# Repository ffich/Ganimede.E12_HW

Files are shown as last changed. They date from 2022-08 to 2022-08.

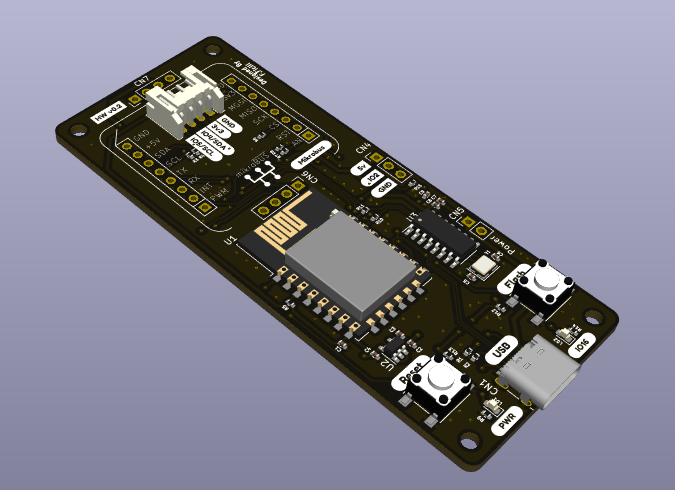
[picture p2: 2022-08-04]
50_3D/Ganimede.E12.png

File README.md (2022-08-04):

# Ganimede.E12_HW
Public repo for ganimede.E12 hardware project.

# What Ganimede is?
The Ganimede is a family of fancy development boards based on ESP8266 and ESP32 SoC from EspressIf.
The idea behind Ganimede is that I started to be bored of soldering, breadboarding and, more in general, to have messy connection between my development board and the sensor and actuators I needed for my experiments and projects.
Additionally, after the experience with Mercury System, I decided to not to do again such a crazy thing in which I had to make all the HW and SW, as it required literally hundreds of days and it's not sustainable (and even if it would be, Anna would probably kill me). Moreover, I do love C, but I understand that this is not the same for everybody and is also a bit limiting, so welcome to Python and Javascript. Last but not least, I wanted to have something really cheap, that can be used by me, friends and (possibly) others.
So, in the end, Ganimede is a development board with the following characteristics:

1. It's based on ESP SoC with integrated peripherals like WiFi, BT and USB.
2. It carries some sockets/connectors that allow to use well known standards (Mikroe MikroBUS, SeedStudio grove, others), so no more messy connections with sensor/actuators around your desk.
3. Can be programmed in C/C++, Python and Javascript.
4. It's really cheap.
5. It's open hardware, I will share schematics and design files.
6. It's really simple to use.

# Ganimede.E12
Ganimede.E12 is the version based on ESP8266 (more specifically on the ESP-12 module by AI-Thinker). The hardware details of Ganimede.E12 are resumed in the picture below:

HwDetails

## Main characteristics of Ganimede.E12:
- USB connection for communication, Power and Flashing
- WiFi
- 11x GPIO
- 2x User LEDs
- 2x User buttons
- 1x MikroBUS Socket
- 1x Grove Connector
- 1x Neopixel/1-wire Connector
- 2x OLED Connectors

If you want more information you can have a look at the [Ganimede.E12 Datasheet](https://2492ae4f-d323-49c0-bc1e-8d5936f83a9d.usrfiles.com/ugd/2492ae_11933c1aee514b55b51fd540d7772119.pdf) and to the [Ganimede.E12 Product Page](https://frafich.wixsite.com/jupitersystem/product-page/ganimede-e12).

# Ganimede.E12 HW project
This repo contains the full HW project of Ganimede.E12, with the traditional file structure I use on my HW projects, and more specifically:
- 10_PCB: contains the Kicad 6.x project of the board. The **jlcpcb** folder contains all the files needed for making the board using JLCPCB service.
- 20_SCH: contains the board's schematic in PDF.
- 30_BOMS: contains a fancy iBOM (made using the iBOM plugin by [https://github.com/openscopeproject](https://github.com/openscopeproject)) and a more traditional BOM file.
- 40_GERBERS: contains Gerber and Centronic files. These files allow you to make your own board by yourself or using traditional PCB/Manufacturing services (e.g. PcbWay).
- 50_3D: contains a 3D view of the board.
- 60_LIB: contains some additional 3D files (mostly step) I needed for making the board's 3D.

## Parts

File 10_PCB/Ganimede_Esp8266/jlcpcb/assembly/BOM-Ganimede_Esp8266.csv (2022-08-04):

Comment | Designator | Footprint | LCSC
1k | R14,R9 | R_0402_1005Metric | C11702
Flash | SW1,SW2 | SW_Push_1P1T_NO_6x6mm_H9.5mm | C127509
CH340G | U3 | SOIC-16_3.9x9.9mm_P1.27mm | C14267
100nF | C1,C8,C9 | C_0402_1005Metric | C1525
470pF | C3 | C_0402_1005Metric | C1537
12pF | C5,C6 | C_0402_1005Metric | C1547
10uF | C4,C7 | C_0402_1005Metric | C15525
USB_C | CN1 | USB_C_Receptacle_HRO_TYPE-C-31-M-12 | C165948
Pwr | LD1 | LED_0603_1608Metric | C2286
User | LD2 | LED_0603_1608Metric | C2288
470 | R10,R11 | R_0402_1005Metric | C25117
100k | R8 | R_0402_1005Metric | C25741
10k | R12,R13,R15,R3,R4,R5,R6 | R_0402_1005Metric | C25744
220k | R7 | R_0402_1005Metric | C25767
5k1 | R1,R2 | R_0402_1005Metric | C25905
1uF | C2 | C_0402_1005Metric | C52923
ESP-12F | U1 | ESP-12E | C82891
Crystal | Y1 | Crystal_SMD_3225-4Pin_3.2x2.5mm | C9002
SPX3819M5-L-3-3 | U2 | SOT-23-5 | C9055

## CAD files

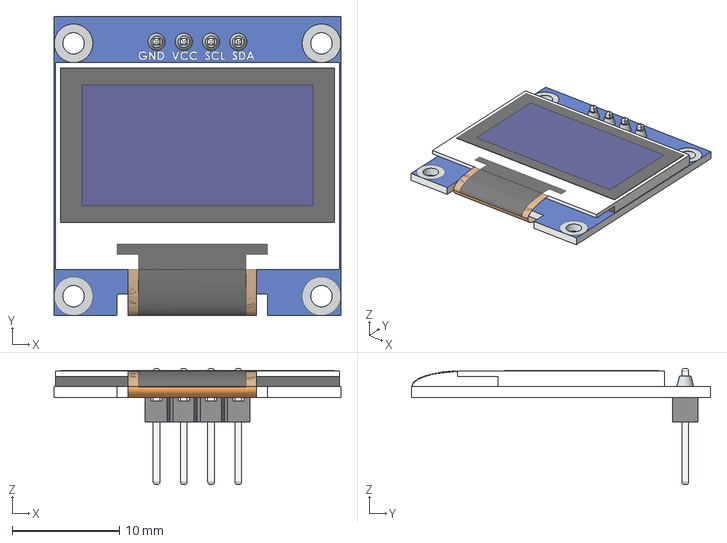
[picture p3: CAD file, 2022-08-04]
60_LIB/30_3d/OLED-128x64-0.96.step
26.7 x 27.9 x 10.8 mm

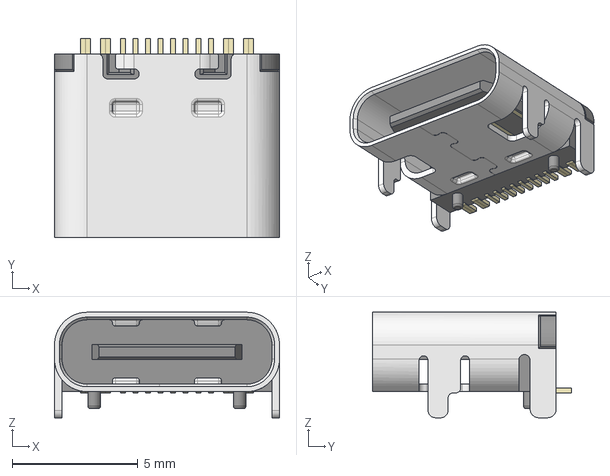
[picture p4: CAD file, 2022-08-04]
60_LIB/30_3d/HRO_TYPE-C-31-M-12.step
8.95 x 7.90 x 4.20 mm

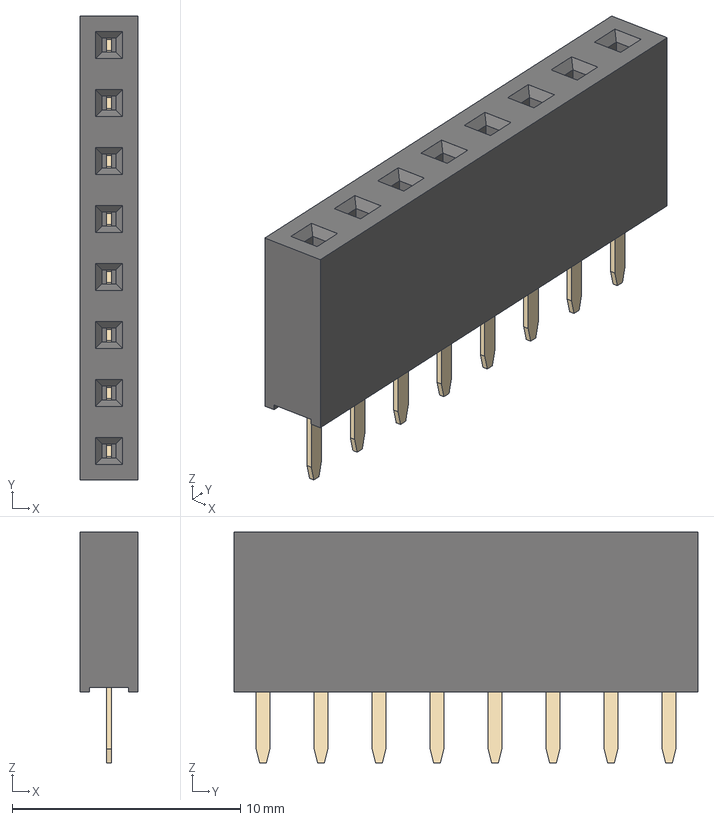
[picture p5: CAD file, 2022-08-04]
60_LIB/30_3d/PinSocket_1x08_P2.54mm_Vertical.step
2.54 x 20.3 x 10.1 mm

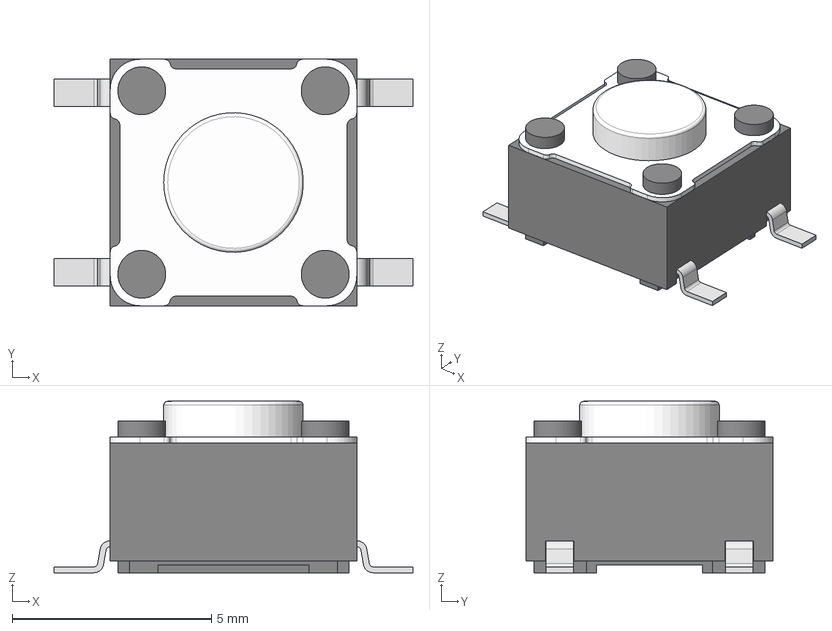
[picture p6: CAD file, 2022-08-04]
60_LIB/30_3d/430182043816 (rev1).stp
9.00 x 6.20 x 4.30 mm

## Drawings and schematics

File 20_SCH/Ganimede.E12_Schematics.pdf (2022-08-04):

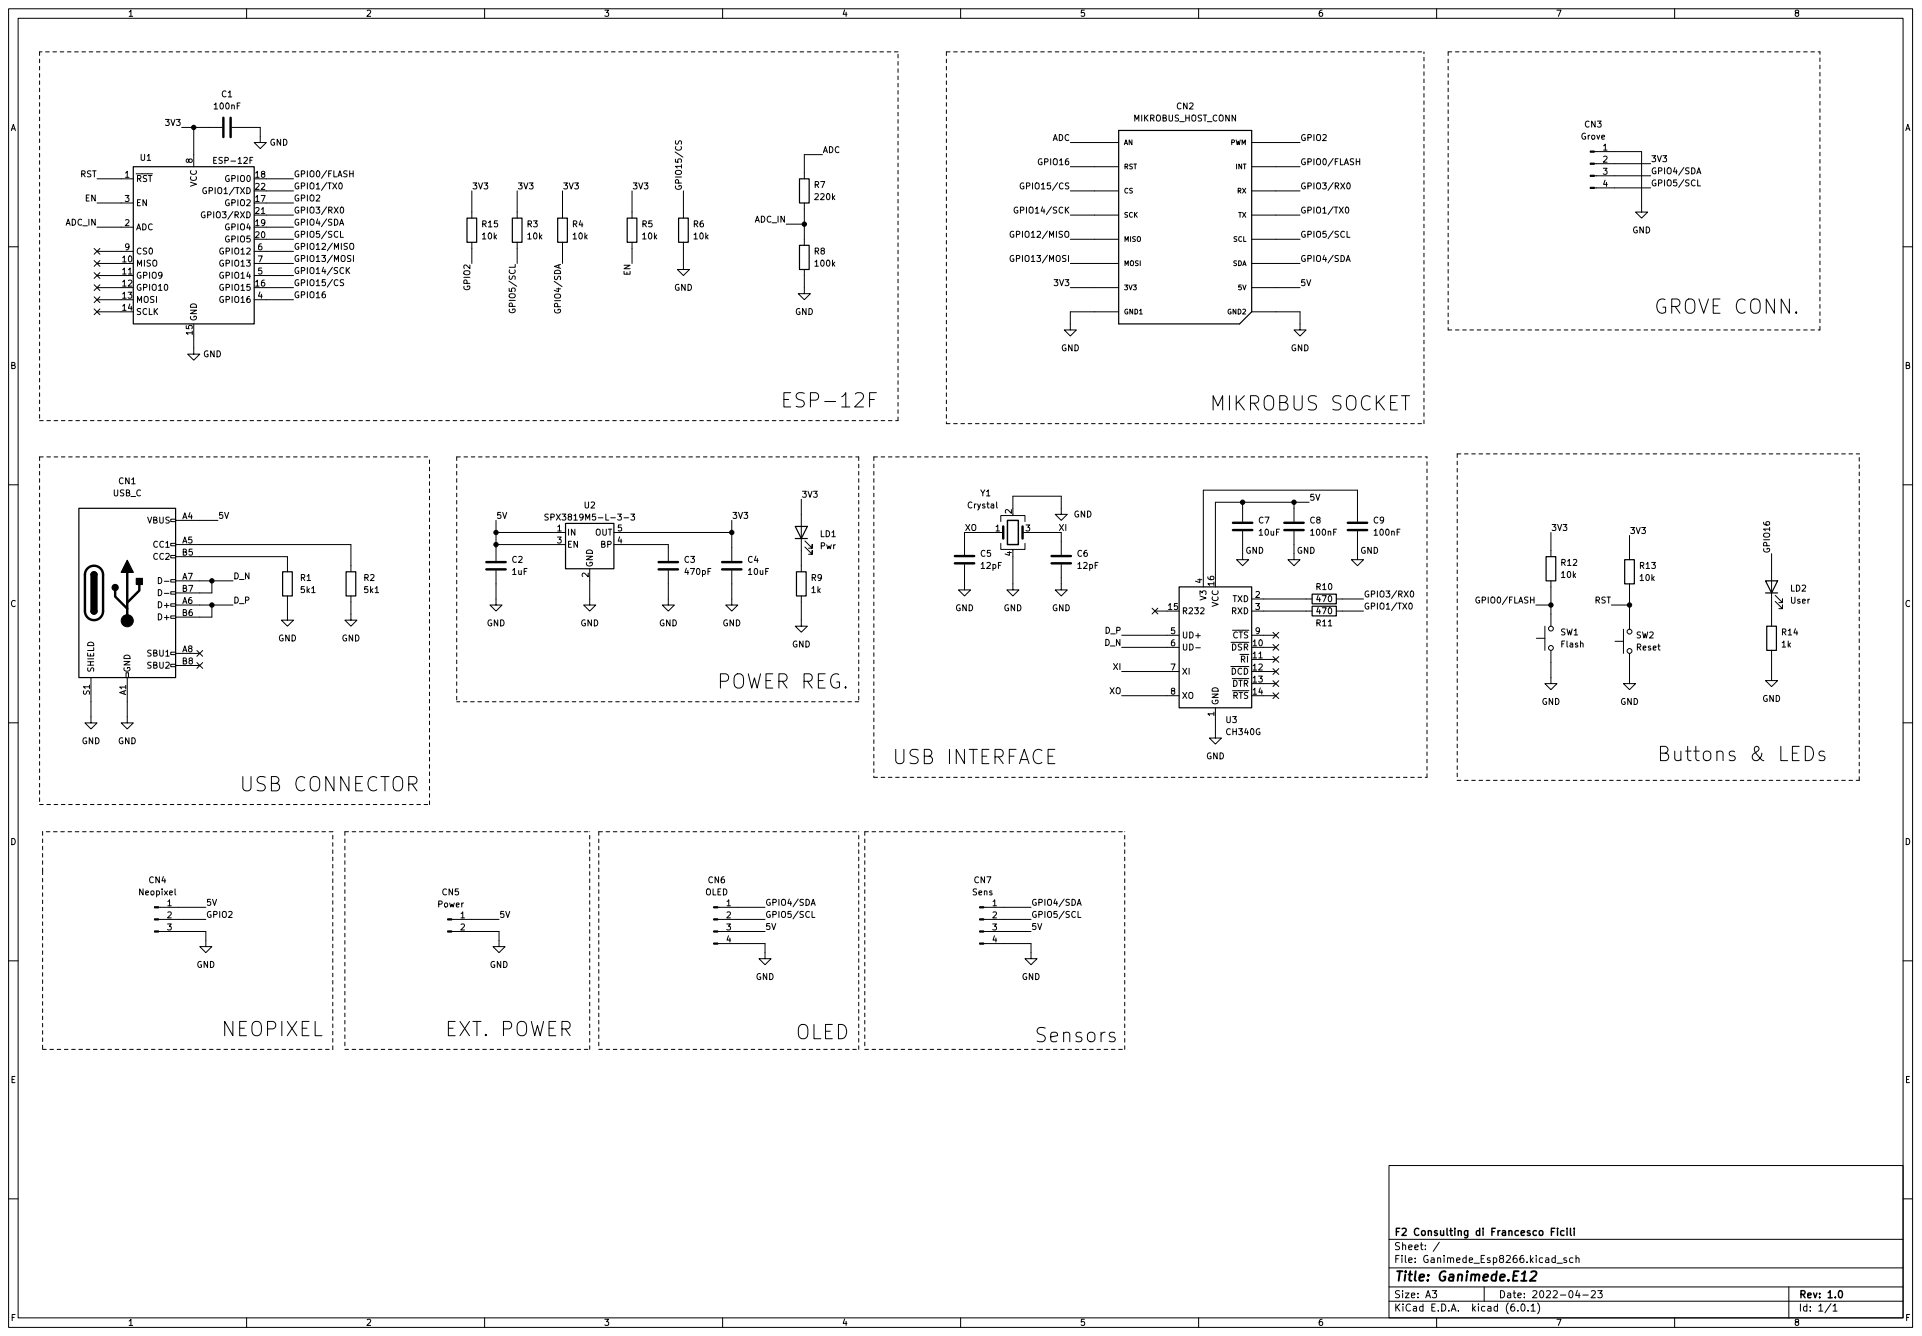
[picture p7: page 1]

2 EN 3 BP 4 OUT 5 U2 SPX3819M5-L-3-3 GND

1 ~{DSR}10 ~{RI}11 ~{DCD}12 ~{DTR}13 ~{RTS}14 R232 15 VCC 16 TXD 2 RXD 3 V3

4 UD+ 5 UD- 6 XI 7 XO 8 ~{CTS} 9 U3CH340G

File: Ganimede_Esp8266.kicad_sch Sheet: / F2 Consulting di Francesco Ficili

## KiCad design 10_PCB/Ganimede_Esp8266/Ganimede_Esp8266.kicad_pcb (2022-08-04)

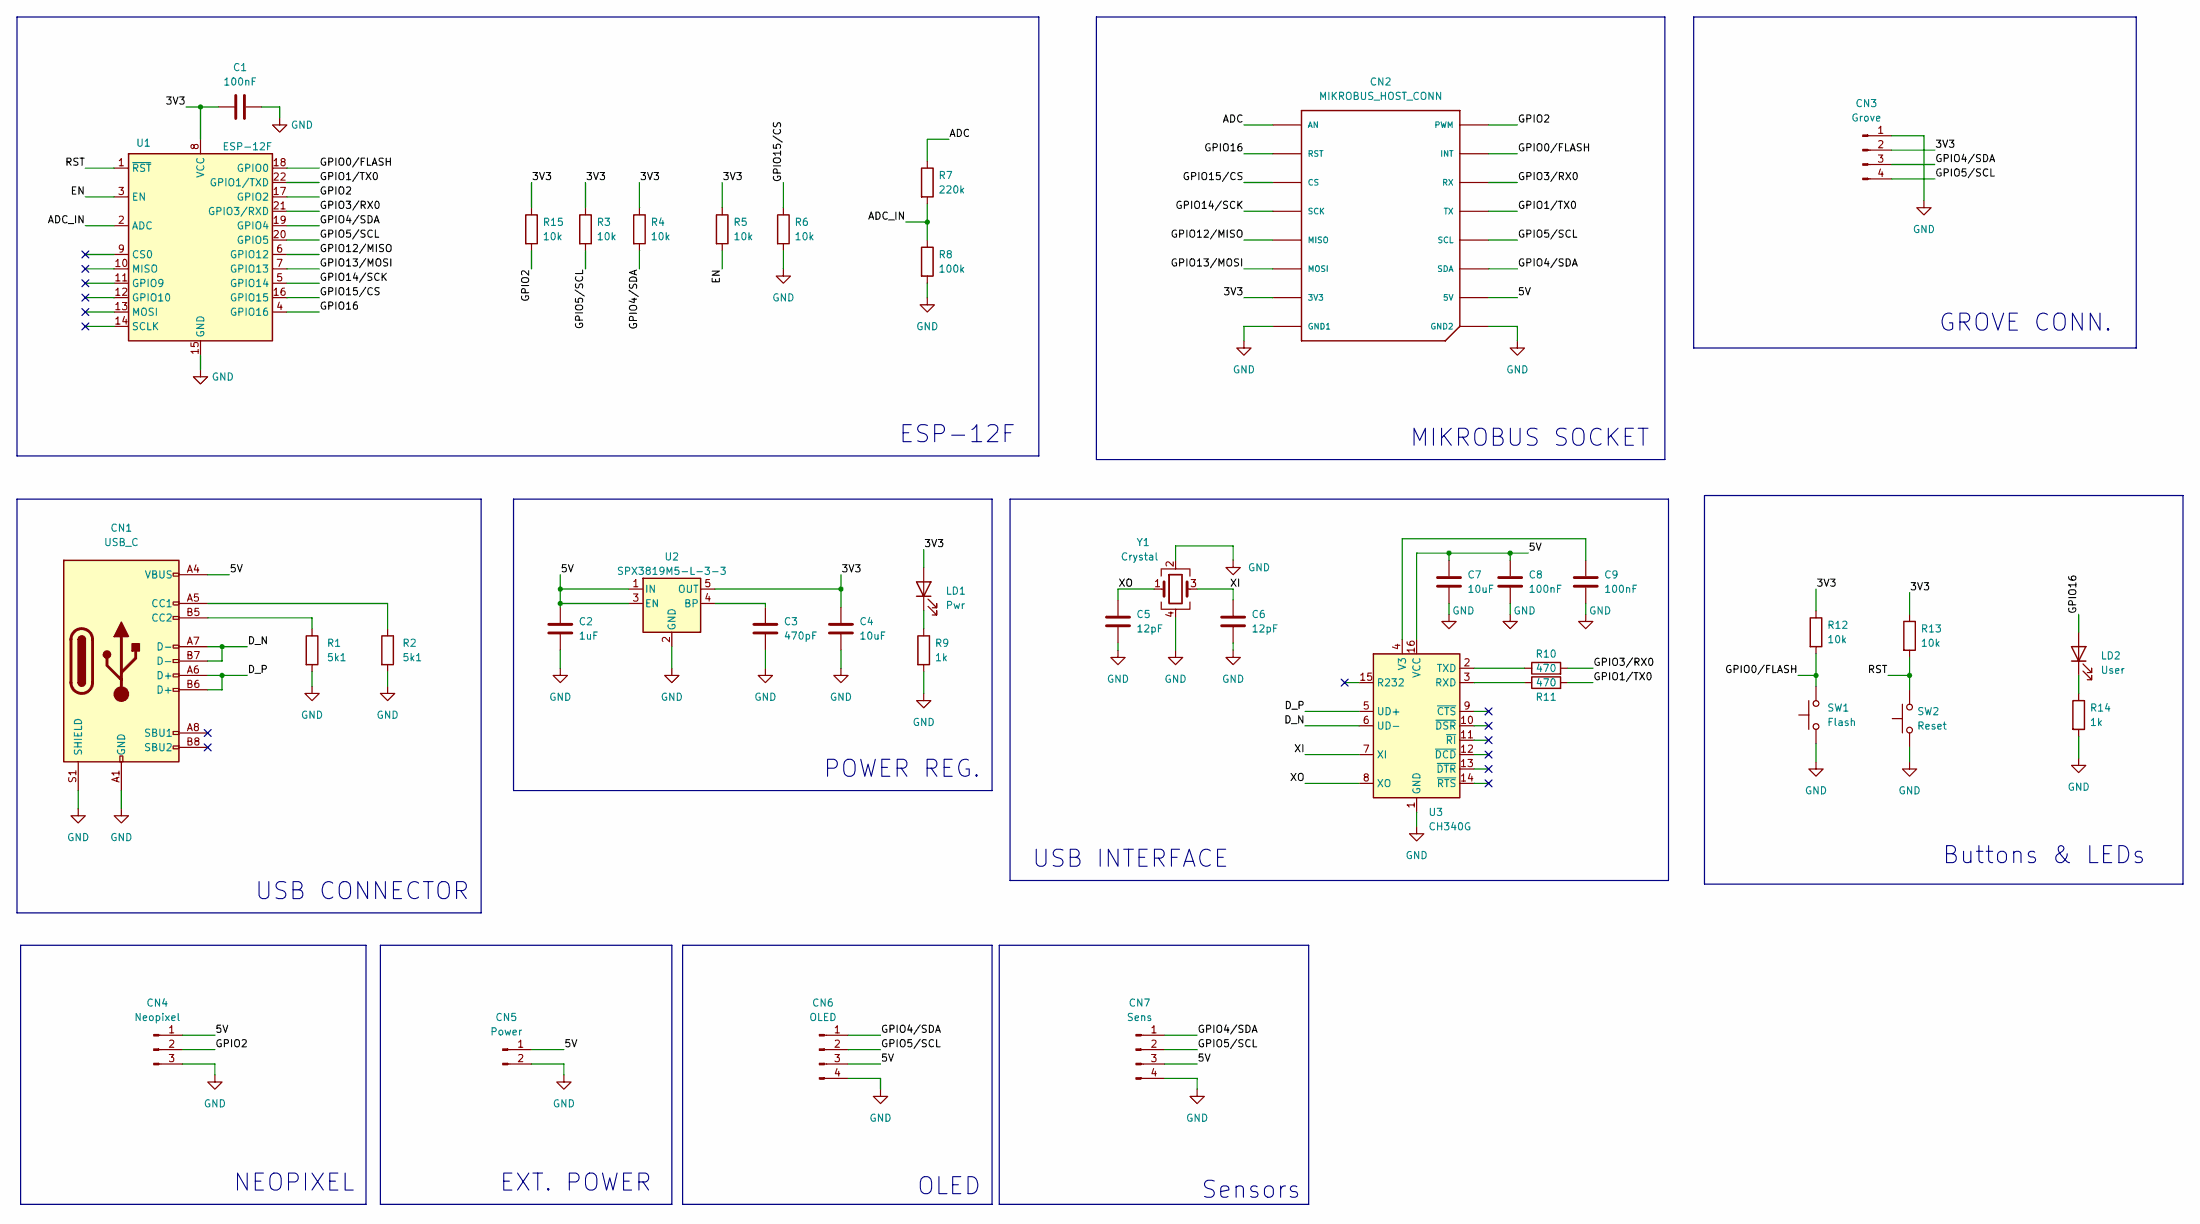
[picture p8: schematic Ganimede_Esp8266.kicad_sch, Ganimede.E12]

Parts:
C1, C8, C9: 100nF; C_0402_1005Metric; LCSC C1525
C2: 1uF; C_0402_1005Metric; LCSC C52923
C3: 470pF; C_0402_1005Metric; LCSC C1537
C4, C7: 10uF; C_0402_1005Metric; LCSC C15525
C5, C6: 12pF; C_0402_1005Metric; LCSC C1547
CN1: USB_C; USB_C_Receptacle_HRO_TYPE-C-31-M-12; LCSC C165948
CN2: MIKROBUS_HOST_CONN
CN3: Grove; JST_PH_S4B-PH-K_1x04_P2.00mm_Horizontal
CN4: Neopixel; PinHeader_1x03_P2.54mm_Vertical
CN5: Power; PinHeader_1x02_P2.54mm_Vertical
CN6: OLED; PinHeader_1x04_P2.54mm_Vertical
CN7: Sens; PinHeader_1x04_P2.54mm_Vertical
LD1: Pwr; LED_0603_1608Metric; LCSC C2286
LD2: User; LED_0603_1608Metric; LCSC C2288
R1, R2: 5k1; R_0402_1005Metric; LCSC C25905
R3, R4, R5, R6, R12, R13, R15: 10k; R_0402_1005Metric; LCSC C25744
R7: 220k; R_0402_1005Metric; LCSC C25767
R8: 100k; R_0402_1005Metric; LCSC C25741
R9, R14: 1k; R_0402_1005Metric; LCSC C11702
R10, R11: 470; R_0402_1005Metric; LCSC C25117
SW1: Flash; SW_Push_1P1T_NO_6x6mm_H9.5mm; LCSC C127509
SW2: Reset; SW_Push_1P1T_NO_6x6mm_H9.5mm; LCSC C127509
U1: ESP-12F; ESP-12E; LCSC C82891
U2: SPX3819M5-L-3-3; SOT-23-5; LCSC C9055
U3: CH340G; SOIC-16_3.9x9.9mm_P1.27mm; LCSC C14267
Y1: Crystal; Crystal_SMD_3225-4Pin_3.2x2.5mm; LCSC C9002

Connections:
/3V3: C1.1, C4.1, CN2.P7 (3V3), CN3.2, LD1.2 (A), R3.1, R4.1, R5.1, R12.1, R13.1, R15.1, U1.8 (VCC), U2.5 (OUT)
/5V: C2.1, C7.1, C8.1, CN1.A4 (VBUS), CN1.A9 (VBUS), CN1.B4 (VBUS), CN1.B9 (VBUS), CN2.P10 (5V), CN4.1, CN5.1, CN6.3, CN7.3, U2.1 (IN), U2.3 (EN), U3.16 (VCC)
/ADC: CN2.P1 (AN), R7.1
/ADC_IN: R7.2, R8.1, U1.2 (ADC)
/D_N: CN1.A7 (D-), CN1.B7 (D-), U3.6 (UD-)
/D_P: CN1.A6 (D+), CN1.B6 (D+), U3.5 (UD+)
/EN: R5.2, U1.3 (EN)
/GPIO0/FLASH: CN2.P15 (INT), R12.2, SW1.2, U1.18 (GPIO0)
/GPIO1/TX0: CN2.P13 (TX), R11.2, U1.22 (GPIO1/TXD)
/GPIO2: CN2.P16 (PWM), CN4.2, R15.2, U1.17 (GPIO2)
/GPIO3/RX0: CN2.P14 (RX), R10.2, U1.21 (GPIO3/RXD)
/GPIO4/SDA: CN2.P11 (SDA), CN3.3, CN6.1, CN7.1, R4.2, U1.19 (GPIO4)
/GPIO5/SCL: CN2.P12 (SCL), CN3.4, CN6.2, CN7.2, R3.2, U1.20 (GPIO5)
/GPIO12/MISO: CN2.P5 (MISO), U1.6 (GPIO12)
/GPIO13/MOSI: CN2.P6 (MOSI), U1.7 (GPIO13)
/GPIO14/SCK: CN2.P4 (SCK), U1.5 (GPIO14)
/GPIO15/CS: CN2.P3 (CS), R6.1, U1.16 (GPIO15)
/GPIO16: CN2.P2 (RST), LD2.2 (A), U1.4 (GPIO16)
/RST: R13.2, SW2.2, U1.1 (~RST)
/XI: C6.1, U3.7 (XI), Y1.3
/XO: C5.1, U3.8 (XO), Y1.1
GND: C1.2, C2.2, C3.2, C4.2, C5.2, C6.2, C7.2, C8.2, C9.2, CN1.A1 (GND), CN1.A12 (GND), CN1.B1 (GND), CN1.B12 (GND), CN1.S1 (SHIELD), CN2.P8 (GND1), CN2.P9 (GND2), CN3.1, CN4.3, CN5.2, CN6.4, CN7.4, R1.2, R2.2, R6.2, R8.2, R9.2, R14.2, SW1.1, SW2.1, U1.15 (GND), U2.2 (GND), U3.1 (GND), Y1.2, Y1.4
unnamed: C3.1, U2.4 (BP)
unnamed: C9.1, U3.4 (V3)
unnamed: CN1.A5 (CC1), R2.1
unnamed: CN1.B5 (CC2), R1.1
unnamed: LD1.1 (K), R9.1
unnamed: LD2.1 (K), R14.1
unnamed: R10.1, U3.2 (TXD)
unnamed: R11.1, U3.3 (RXD)

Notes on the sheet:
GROVE CONN.
ESP-12F
Buttons & LEDs
POWER REG.
OLED
USB CONNECTOR
EXT. POWER
Sensors
NEOPIXEL
MIKROBUS SOCKET
USB INTERFACE

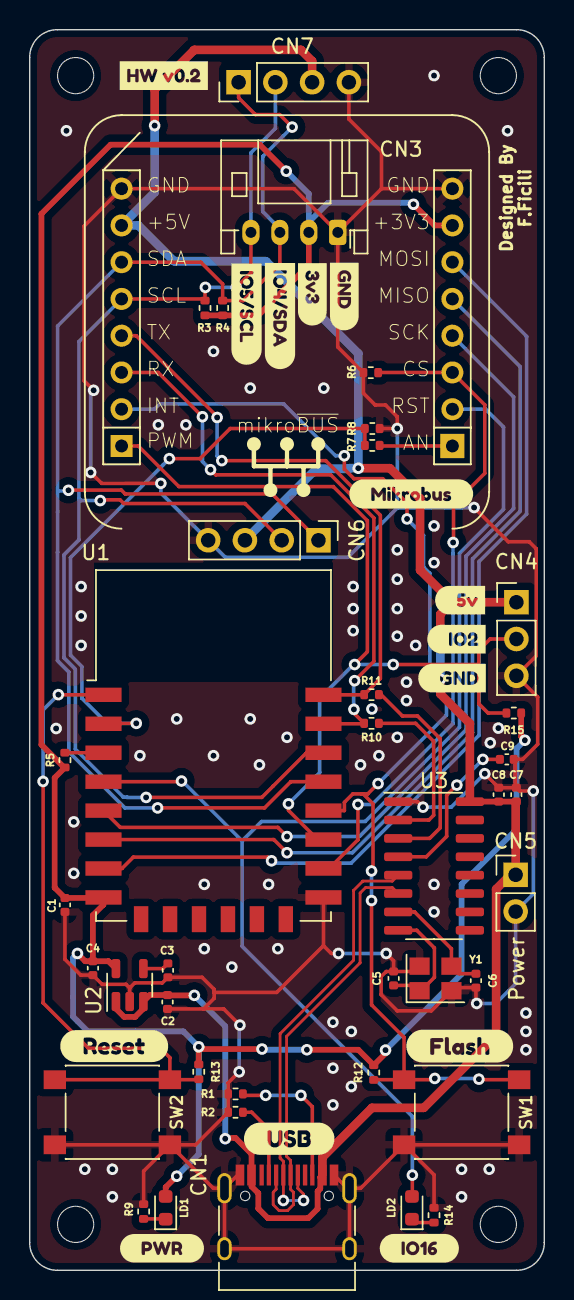
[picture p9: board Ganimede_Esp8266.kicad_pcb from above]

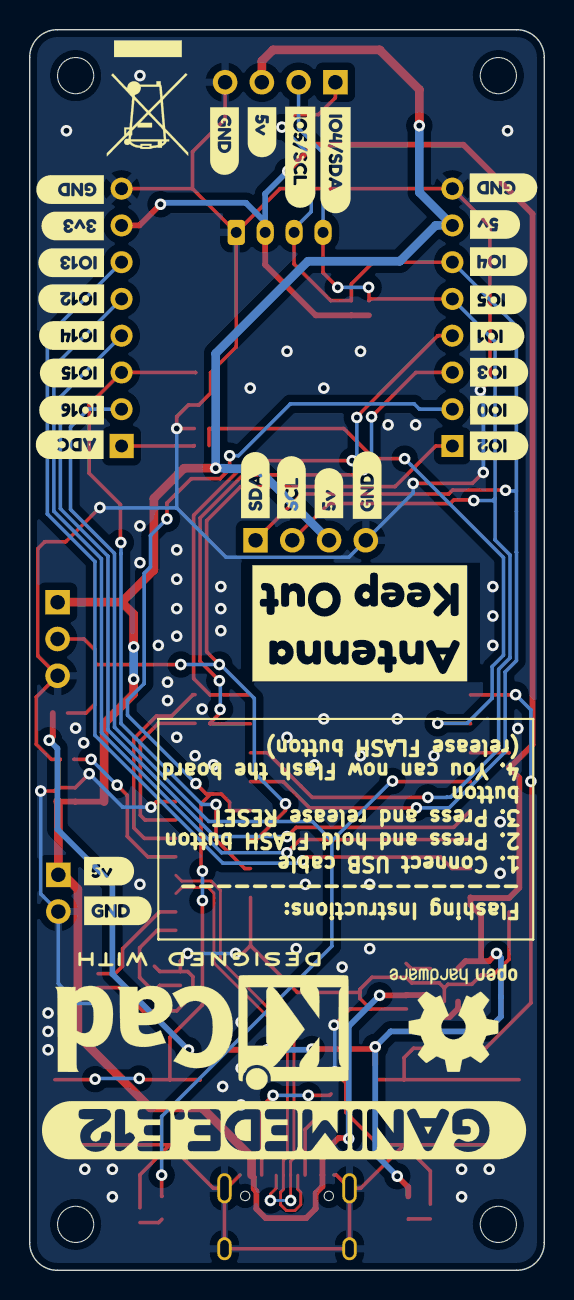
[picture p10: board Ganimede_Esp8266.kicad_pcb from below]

Board: 2 copper layers, 35.6 x 85.7 mm, 81 parts (28 on the bottom side), 30 nets.

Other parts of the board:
kibuzzard-62924A8F: G***; kibuzzard-62924A8F
kibuzzard-62924A99: G***; kibuzzard-62924A99
kibuzzard-62925DA5: G***; kibuzzard-62925DA5
kibuzzard-62925DB7: G***; kibuzzard-62925DB7
kibuzzard-627569F9: G***; kibuzzard-627569F9
kibuzzard-629249FD: G***; kibuzzard-629249FD
kibuzzard-629255AA: G***; kibuzzard-629255AA
kibuzzard-629255B3: G***; kibuzzard-629255B3
kibuzzard-629255BF: G***; kibuzzard-629255BF
kibuzzard-629255D4: G***; kibuzzard-629255D4
kibuzzard-629255EA: G***; kibuzzard-629255EA
kibuzzard-629255F7: G***; kibuzzard-629255F7
kibuzzard-629256A8: G***; kibuzzard-629256A8
kibuzzard-629258C9, kibuzzard-629258C9#2: G***; kibuzzard-629258C9
kibuzzard-629258DB, kibuzzard-629258DB#2: G***; kibuzzard-629258DB
kibuzzard-629263D2, kibuzzard-629263D2#2: G***; kibuzzard-629263D2
kibuzzard-629263EA: G***; kibuzzard-629263EA
kibuzzard-6275539F: G***; kibuzzard-6275539F
kibuzzard-6292541E: G***; kibuzzard-6292541E
kibuzzard-6292551A: G***; kibuzzard-6292551A
kibuzzard-6292567C: G***; kibuzzard-6292567C
kibuzzard-6292569E: G***; kibuzzard-6292569E
kibuzzard-6292591F, kibuzzard-6292591F#2: G***; kibuzzard-6292591F
kibuzzard-62755375: G***; kibuzzard-62755375
kibuzzard-62755551: G***; kibuzzard-62755551
kibuzzard-62769624: G***; kibuzzard-62769624
kibuzzard-62925408: G***; kibuzzard-62925408
kibuzzard-62925415: G***; kibuzzard-62925415
kibuzzard-62925591: G***; kibuzzard-62925591
kibuzzard-62925659: G***; kibuzzard-62925659
kibuzzard-62925667: G***; kibuzzard-62925667
kibuzzard-62925672: G***; kibuzzard-62925672
kibuzzard-62925687: G***; kibuzzard-62925687
kibuzzard-62925693: G***; kibuzzard-62925693
kibuzzard-62925732: G***; kibuzzard-62925732
kibuzzard-62925915: G***; kibuzzard-62925915
kibuzzard-62926402: G***; kibuzzard-62926402
kibuzzard-62926416: G***; kibuzzard-62926416

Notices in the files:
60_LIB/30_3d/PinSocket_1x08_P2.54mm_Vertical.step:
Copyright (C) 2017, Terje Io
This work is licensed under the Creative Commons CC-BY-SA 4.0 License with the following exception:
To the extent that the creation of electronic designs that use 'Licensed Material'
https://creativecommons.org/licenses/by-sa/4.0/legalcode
